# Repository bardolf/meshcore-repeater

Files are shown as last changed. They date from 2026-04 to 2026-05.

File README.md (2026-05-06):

# MeshCore Repeater

Solar-powered MeshCore repeater node — 3D-printable enclosure, bill of materials, and build notes for [rep.skybit.cz](https://rep.skybit.cz).

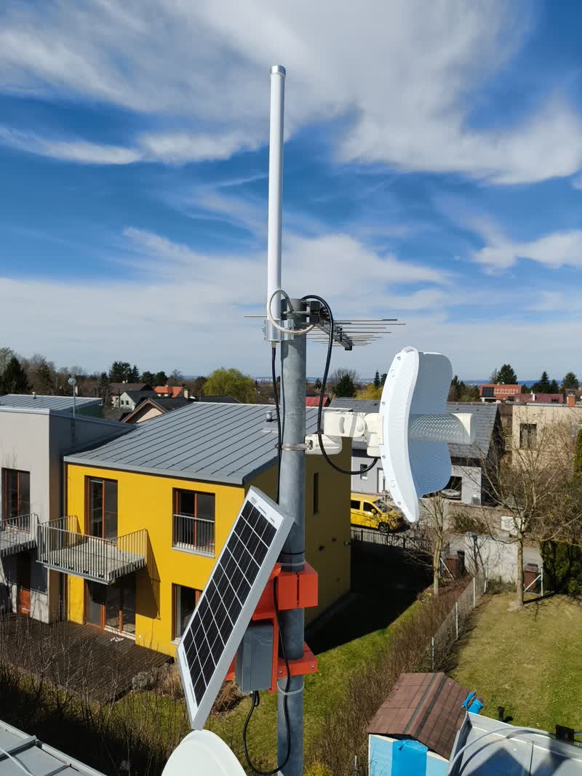
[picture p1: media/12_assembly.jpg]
Repeater mounted on a mast


<p align="center">
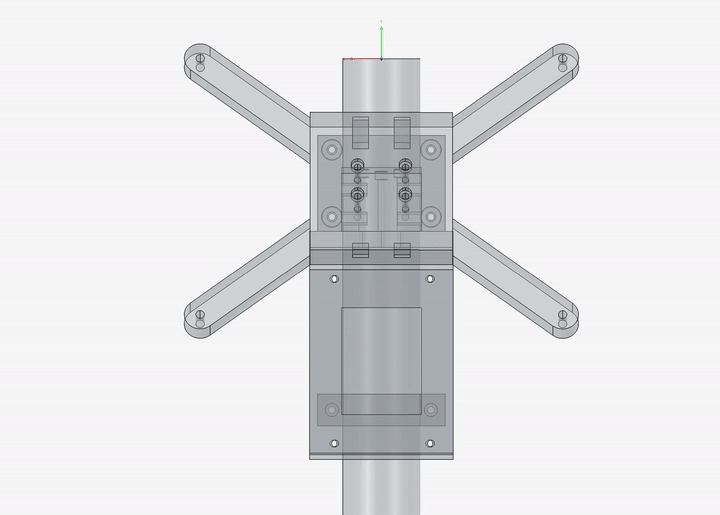
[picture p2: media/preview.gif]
Repeater preview
  
</p>

## Bill of Materials

| # | Component | Link | Image |
|---|---|---|---|
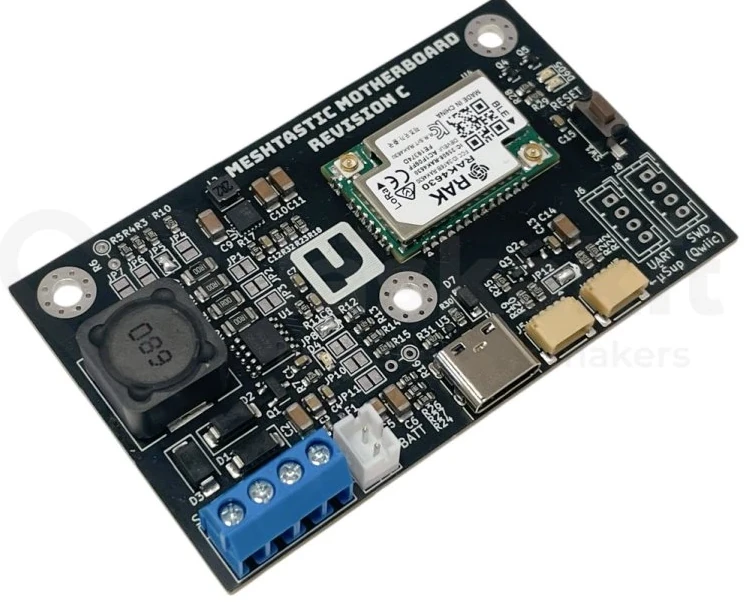
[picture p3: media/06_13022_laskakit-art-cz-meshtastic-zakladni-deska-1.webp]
| 1 | LaskaKit ART-CZ Meshtastic baseboard | [laskakit.cz](https://www.laskakit.cz/--art-cz-meshtastic-zakladni-deska/) |  |
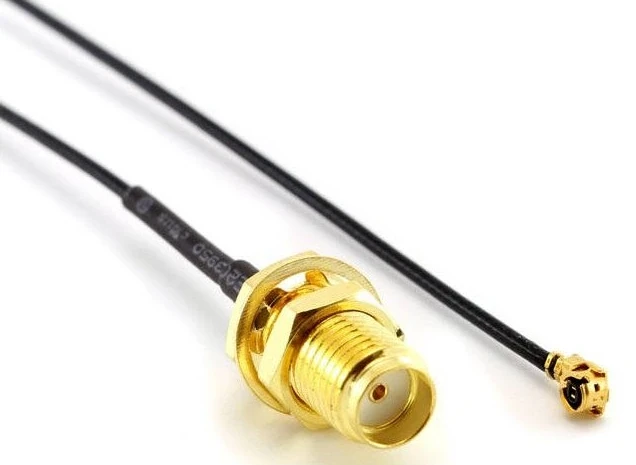
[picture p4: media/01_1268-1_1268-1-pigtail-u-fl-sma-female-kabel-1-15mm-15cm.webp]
| 2 | U.FL to SMA female pigtail (1.13 mm, 15 cm) | [laskakit.cz](https://www.laskakit.cz/pigtail-u-fl-sma-female--kabel-1-13mm--15cm/) |  |
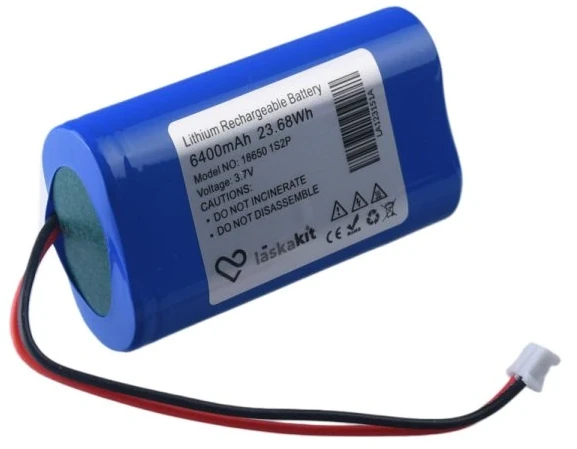
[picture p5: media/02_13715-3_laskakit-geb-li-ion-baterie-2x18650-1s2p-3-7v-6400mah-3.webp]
| 3 | Li-Ion battery pack 2×18650 1S2P 3.7 V 6400 mAh | [laskakit.cz](https://www.laskakit.cz/geb-li-ion-baterie-2x18650-1s2p-3-7v-6400mah/) |  |
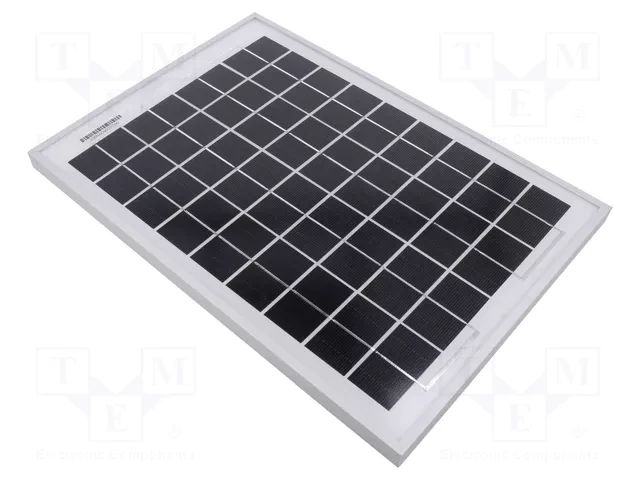
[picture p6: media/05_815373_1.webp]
| 4 | Solar panel CL-SM10P (photovoltaic module) | [tme.eu](https://www.tme.eu/en/details/cl-sm10p/photovoltaic-modules/cellevia-power/) |  |
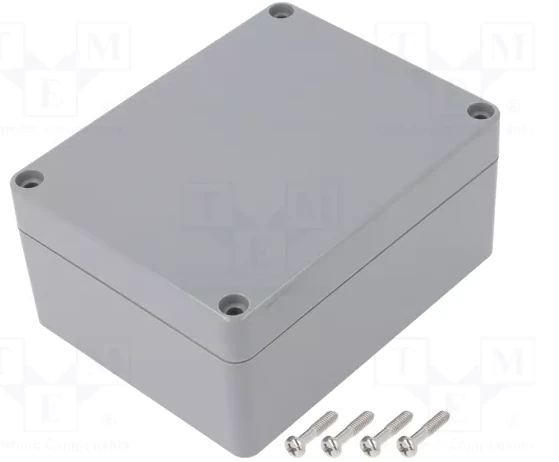
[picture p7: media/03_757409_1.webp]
| 5 | Enclosure A311 IP68 | [tme.eu](https://www.tme.eu/en/details/a311-ip68/multipurpose-enclosures/gainta/) |  |
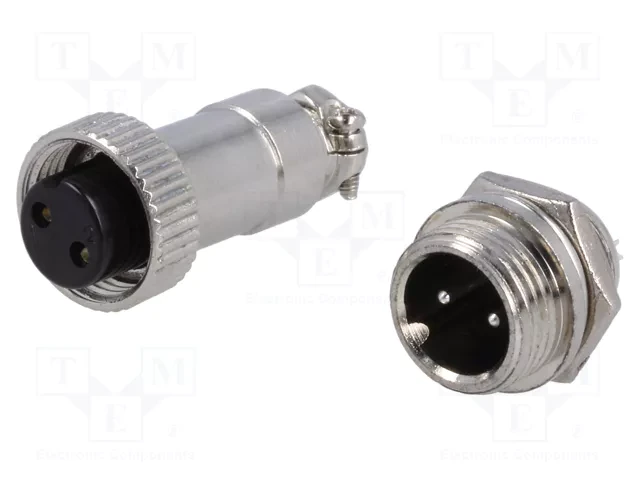
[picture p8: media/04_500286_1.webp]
| 6 | DS1110-01-2B6 microphone connector (for solar input) | [tme.eu](https://www.tme.eu/en/details/ds1110-01-2b6/microphone-connectors/connfly/) |  |
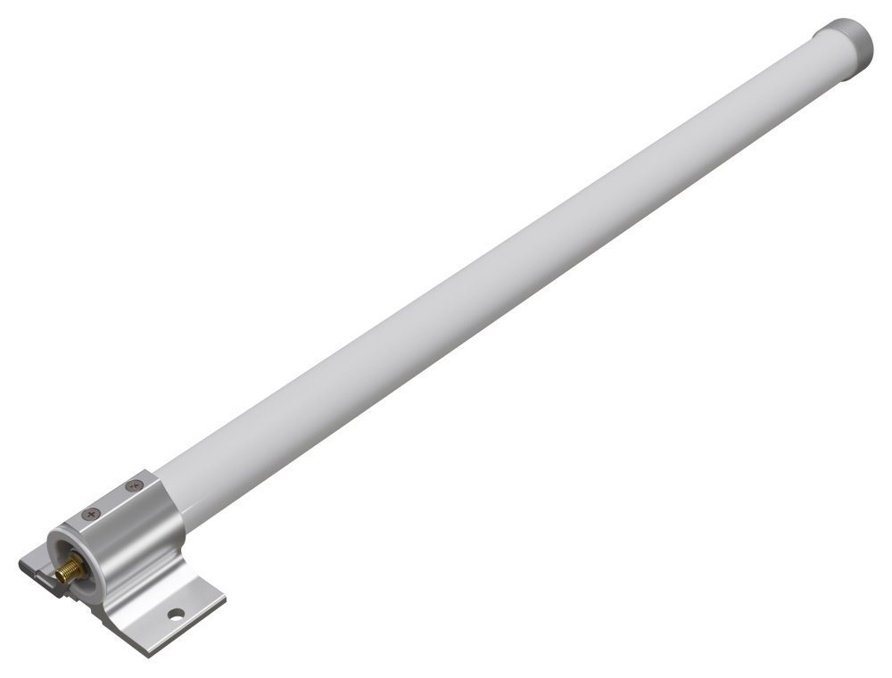
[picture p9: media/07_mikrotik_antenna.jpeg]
| 7 | Mikrotik antenna (or similar 868 MHz) | [i4wifi.cz](https://www.i4wifi.cz/cs/265996) |  |
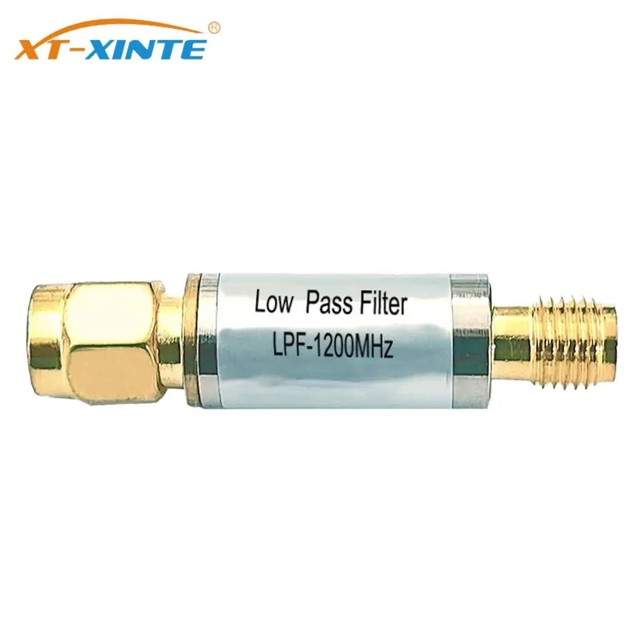
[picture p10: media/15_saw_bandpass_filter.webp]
| 8 | 868 MHz SAW bandpass filter (significantly improves SNR — must-have) | [aliexpress.com](https://www.aliexpress.com/item/1005006381254805.html) |  |

## Assembly

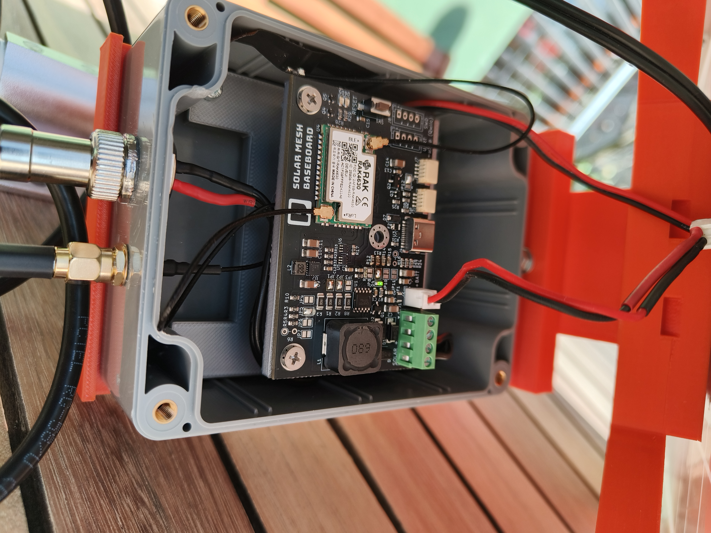
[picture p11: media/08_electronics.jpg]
Electronics inside the enclosure


## 3D Model

The enclosure holder is designed in FreeCAD. Source file: [`model/solar_holder.FCStd`](model/solar_holder.FCStd)

> This is the first version of the design. There are several things I would improve — especially access to some of the screws, etc. But in the end, it holds together and works.

**Printable STL files** (in [`model/stl/`](model/stl/)):

- `solar_holder-arm.stl`
- `solar_holder-arm_back.stl`
- `solar_holder-box_holder.stl`
- `solar_holder-electronics_holder.stl`
- `solar_holder-solar_cross.stl`
- `solar_holder-spacer.stl`
- `solar_holder-spacer_back.stl`

## Important Notes

- The solar panel is tilted at **65°** — optimized for winter months when sunlight is scarce.
- **Never power on the device with antennas disconnected** — this can damage the RF module.
- Watch the **battery polarity** — you may need a JST connector with swapped polarity depending on your battery pack.

## First Pongs & Neighbors

The farthest repeater visible from this node is **85 km** away.

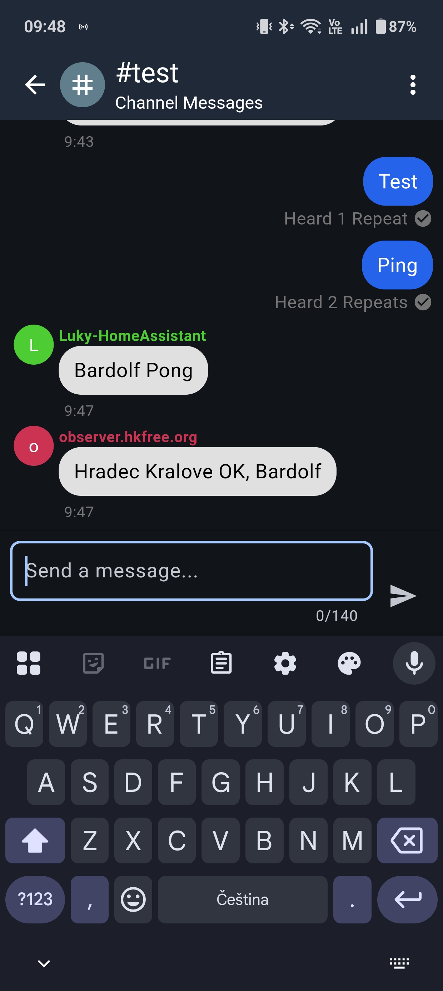
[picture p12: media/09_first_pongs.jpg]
First successful pongs over the mesh network


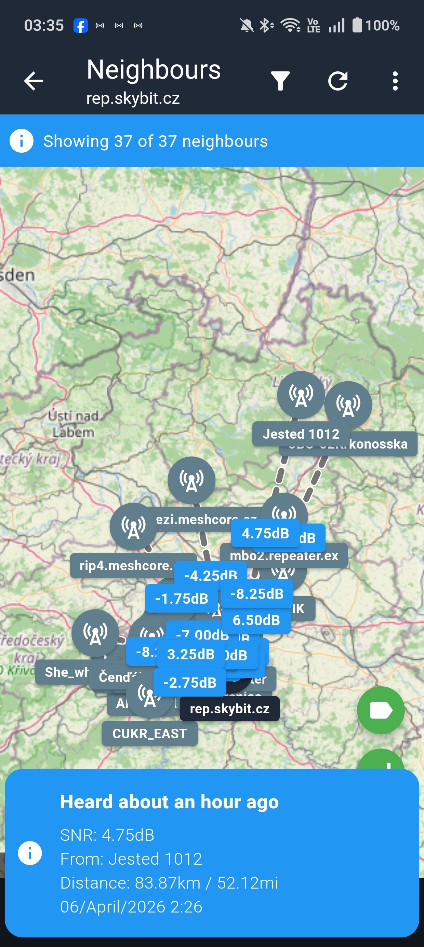
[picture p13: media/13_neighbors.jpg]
Neighbor map showing connected repeaters

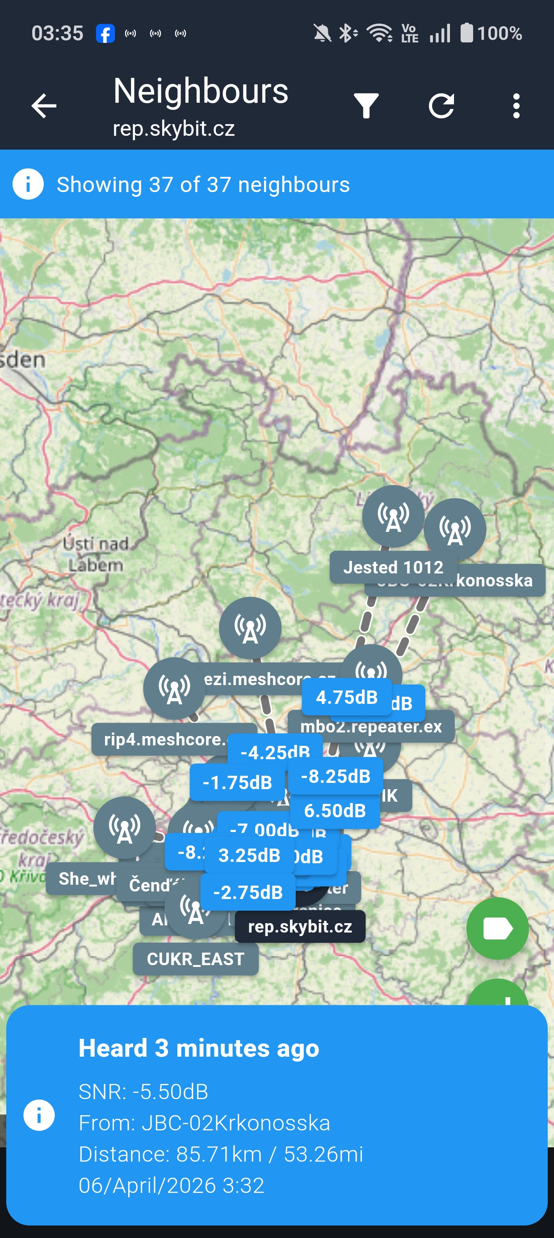
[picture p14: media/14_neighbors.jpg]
Neighbor map showing connected repeaters


## Links

- [MeshCore repeater installation guide](https://meshcore.cz/instalace_repeateru)
- [LaskaKit ART-CZ Meshtastic baseboard](https://www.laskakit.cz/--art-cz-meshtastic-zakladni-deska/)
- [https://mapa.sftr.cz/#/live](https://mapa.sftr.cz/#/live)

## TODO

- [ ] Add detailed assembly instructions with step-by-step photos
- [ ] Document firmware flashing procedure
- [ ] Add wiring diagram
- [ ] Add range test results and coverage map
- [ ] Document power consumption and battery life estimates

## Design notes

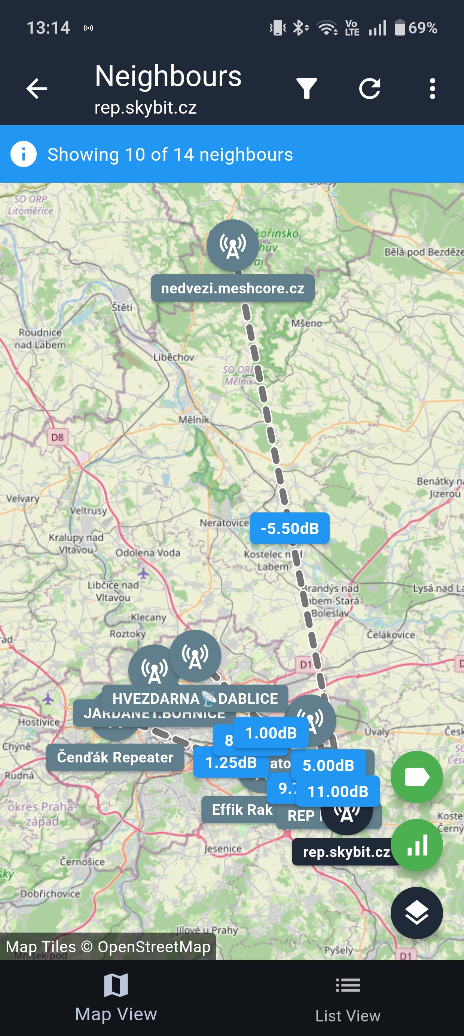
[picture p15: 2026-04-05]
media/10_neighbors.jpg

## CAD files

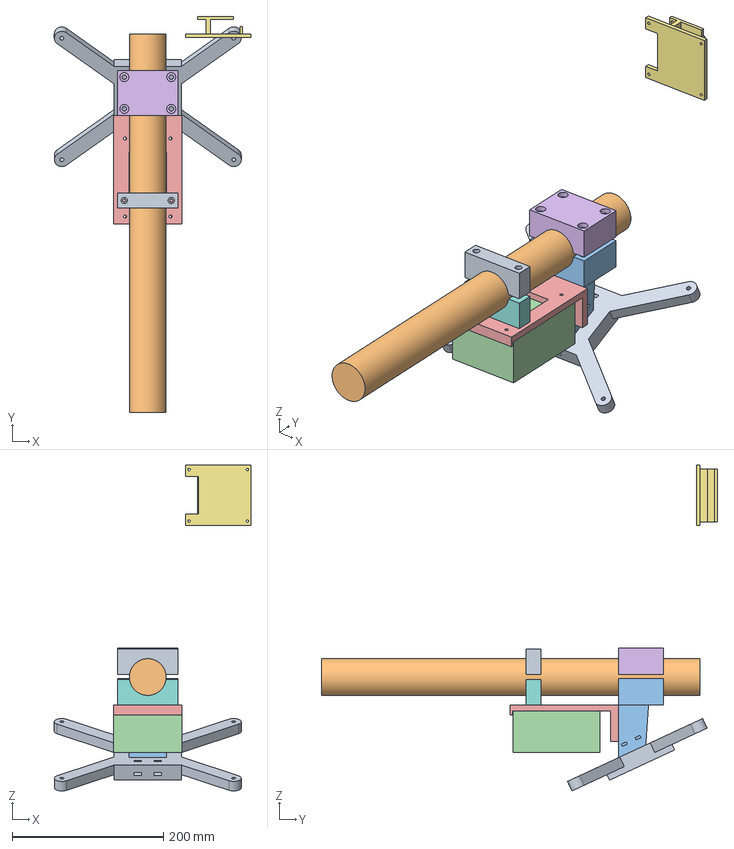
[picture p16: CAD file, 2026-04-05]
model/solar_holder.FCStd
259.5 x 523.0 x 430.5 mm
solar_cross
pole
arm
box simulation
box_holder
arm_back
electronics_holder
spacer
spacer_back

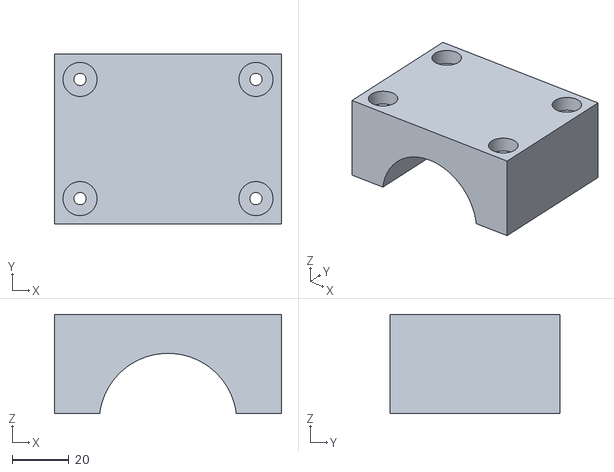
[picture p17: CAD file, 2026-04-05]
model/stl/solar_holder-arm_back.stl
80.0 x 60.0 x 35.0

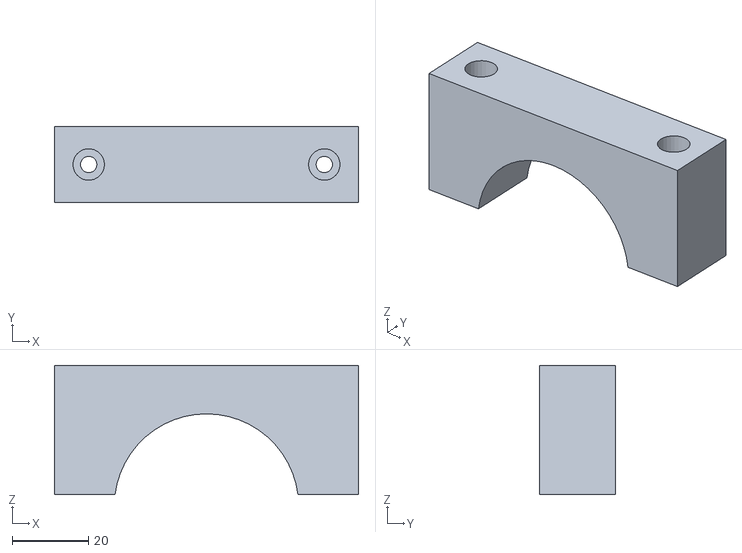
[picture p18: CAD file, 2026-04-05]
model/stl/solar_holder-spacer_back.stl
80.0 x 20.0 x 34.0

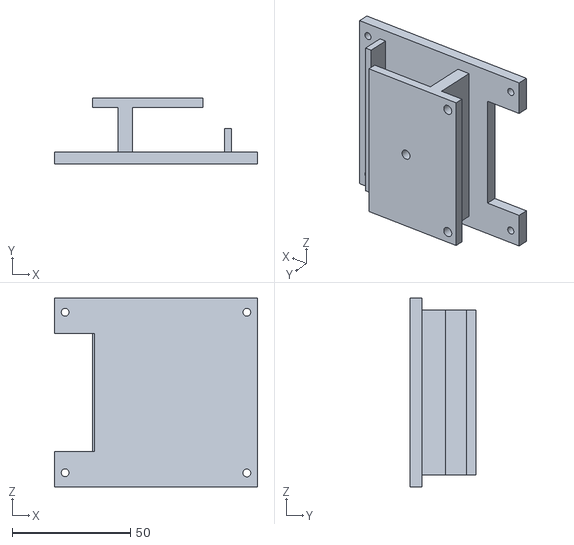
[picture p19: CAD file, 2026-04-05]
model/stl/solar_holder-electronics_holder.stl
86.0 x 28.0 x 80.0

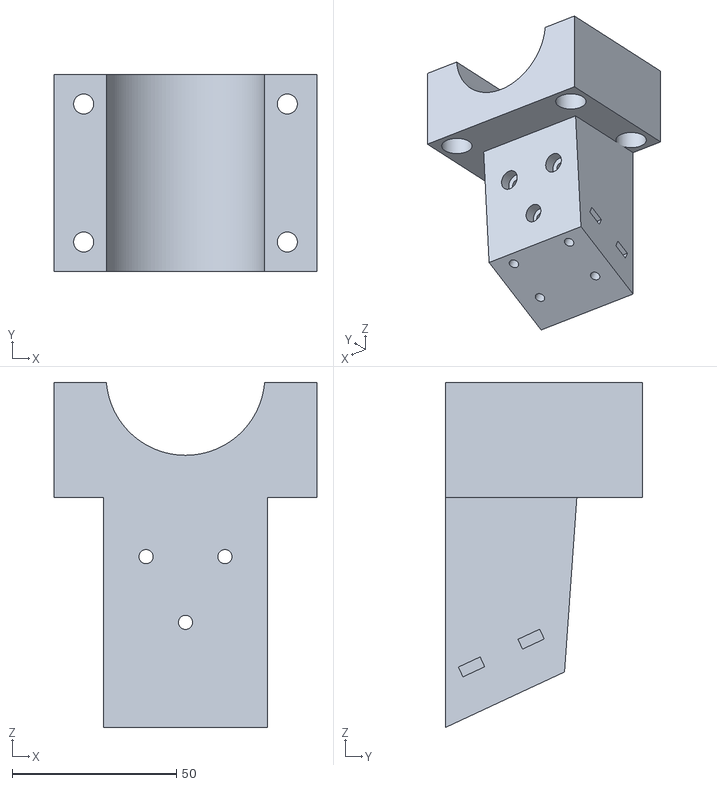
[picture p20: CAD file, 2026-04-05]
model/stl/solar_holder-arm.stl
80.0 x 60.0 x 105.0

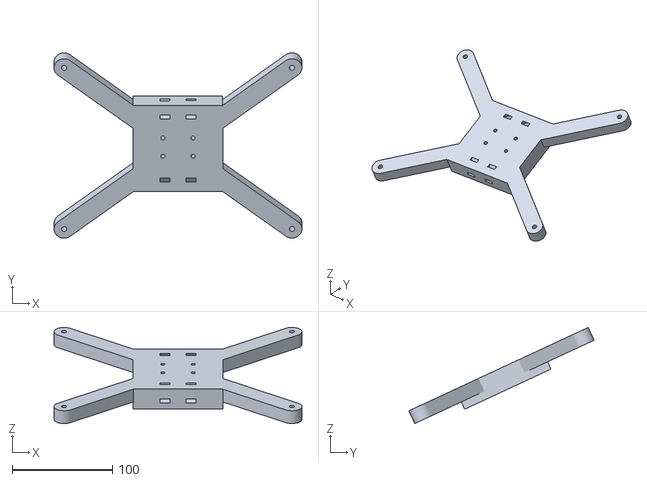
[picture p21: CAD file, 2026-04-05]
model/stl/solar_holder-solar_cross.stl
247.1 x 184.6 x 95.8

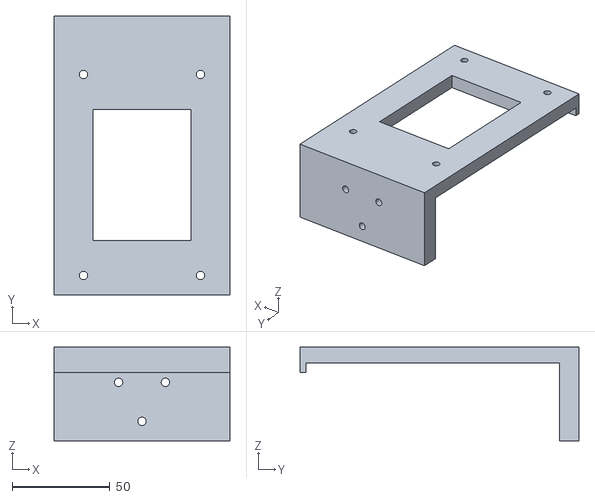
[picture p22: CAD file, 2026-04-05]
model/stl/solar_holder-box_holder.stl
90.0 x 143.0 x 48.0

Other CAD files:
model/stl/solar_holder-spacer.stl
